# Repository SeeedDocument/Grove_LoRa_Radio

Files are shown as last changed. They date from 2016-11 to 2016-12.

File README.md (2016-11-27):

# Grove_LoRa_Radio
Grove LoRa Radio 433MHz SKU: 113060007

Grove LoRa Radio 868MHz SKU: 113060006

Change Log:

- 2016-11-27: create repos by Jiankai.li (jiankai.li@seeed.cc)

## About Seeed

Seeed is a hardware innovation platform for makers to grow inspirations into differentiating products. By working closely with technology providers of all scale, Seeed provides accessible technologies with quality, speed and supply chain knowledge. When prototypes are ready to iterate, Seeed helps productize 1 to 1,000 pcs using in-house engineering, supply chain management and agile manufacture forces. Seeed also team up with incubators, Chinese tech ecosystem, investors and distribution channels to portal Maker startups beyond.

## Contribution

We warmly welcome contribution to this documentation project. You can do this basically by [forking](https://help.github.com/articles/fork-a-repo), committing modifications and then [pulling requests](https://help.github.com/articles/using-pull-requests) (follow the links above for operating guide). Adding change log and your contact into file header is encouraged. Thanks for your contribution.

LICENSE
-------
Copyright (c) 2008-2016 Seeed Development Limited (www.seeedstudio.com / www.seeed.cc)

### Documents and Images
</a><br />
This work (product documents and associated images) are licensed under a <a rel="license" href="http://creativecommons.org/licenses/by-sa/4.0/">Creative Commons Attribution-ShareAlike 4.0 International License</a>. 

### Software Library
All demo software, code examples embedded in the document and any software libraray provided with the product document are licensed under [MIT License](https://github.com/SeeedDoc/WikiMigrationSync/blob/master/MIT_LICENSE "MIT LICENSE") unless otherwise specified.

### Thirdparty content
The resources provided with the product documents also contains datasheets, software examples and other content copyrighted by 3rd party authors and companies. All such items are copyright of respective owners. The use of such items are governed by their respective licenses.

All trademarks are the property of their respective owners.

### To Contact

Write to us at  with subject line "Wiki". Thanks

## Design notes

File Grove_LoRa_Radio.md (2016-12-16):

---
title: Grove - LoRa Radio
category: Communication
bzurl: https://www.seeedstudio.com
oldwikiname: Grove - LoRa Radio
prodimagename: Grove-LoRa Radio.jpg
surveyurl: https://www.research.net/r/Grove_LoRa_Radio
sku:  113060006/113060007
---

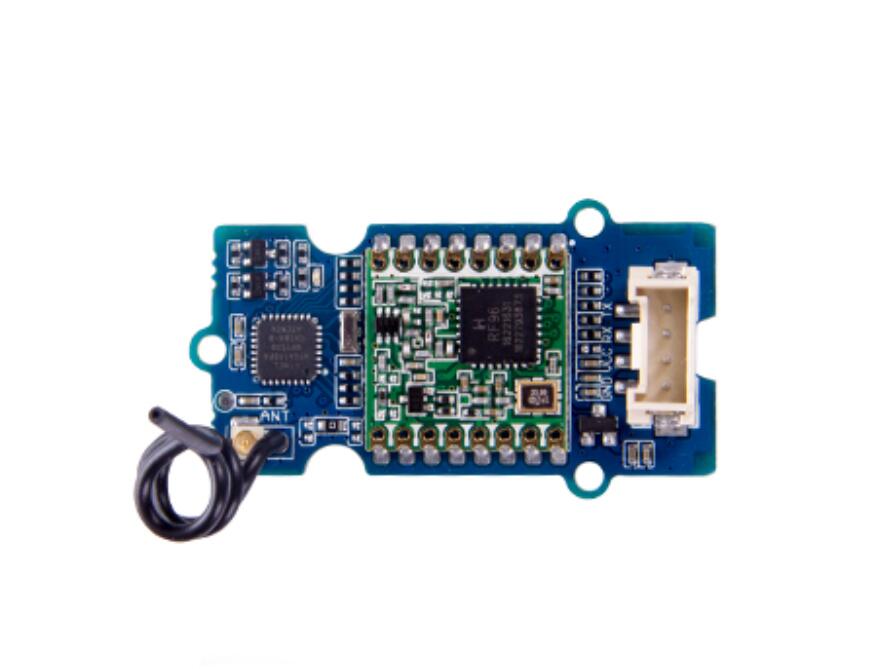
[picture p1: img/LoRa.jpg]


Grove - LoRa Radio is a wireless radio LoRa module with Grove Connector based on SX1276, it integrates richful features, like extra long communication, high penetrability, low consumption and etc.

Grove - LoRa Radio can help people to make their applications adapted in a longstanding, remotely and complex terrain condition. The communication of the distance of two LoRa node at least 2KM in a open field by the default antenna, and simultaneously people can add extra antenna to the reserved port.

Due to the spread spectrum technology, communications with different data rates do not interfere with each other. Data rates range from 0.3 kbps to 50 kbps.

(https://www.seeedstudio.com)

##  Features
---
- Using RFM95 module based on SX1276 LoRa®
- Working Voltage:5V/3.3V
- ~28mA(Avg) @+20dBm continuous transmit
- ~8.4mA(Avg)@standby mode
- ~20mA(Avg) @receive mode, BW-500kHz
- Working Temperature:-20 – 70℃
- Interface:Grove - UART(RX,TX,VCC,GND)
- Simple wire antenna or MHF Connector for external high gain antenna
- Working Frequency:868MHz/433MHz
- +20dBm 100 mW Power Output Capability
- Size:20*40mm
- Rate:0.3kps~50kps
- Ready-to-go Arduino libraries
- Resered MHF antenna connector

##  Interface Function
---

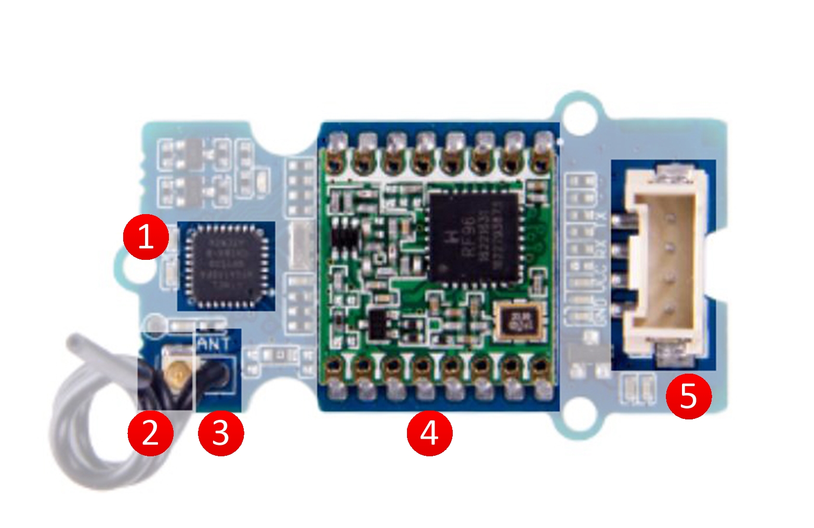
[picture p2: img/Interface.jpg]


1. ATMega168 MCU
2. MHF
3. ANT
4. RFM95 Module
5. Grove Interface

## Application Ideas
---
- Food
- Water
- Safety
- Health
- City IoT
- Sensor networks
- Long distance wireless communication

##Getting Started

After this section, you can make **Grove - LoRa Radio** run with only few steps.

###Preparations

Now we are making a demo for P2P(point to point) communication with the Grove - Lora Radio 433MHz, the Grrove - LoRa Radio 868MHz is the same way to use.

* [Seeeduino Lotus](https://www.seeedstudio.com/Seeeduino-Lotus-ATMega328-Board-with-Grove-Interface-p-1942.html)*2
* [Grove - LoRa Radio 433MHz](https://www.seeedstudio.com/)*2

If this is your first time using [Seeeduino Lotus](https://www.seeedstudio.com/Seeeduino-Lotus-ATMega328-Board-with-Grove-Interface-p-1942.html), please refer to [Seeeduino Lotus's wiki](http://www.seeedstudio.com/wiki/Seeeduino_Lotus_v1.0).

Seeeduino Lotus is fully compatible with Arduino which works as simple as Arduino.

If this is your first time using Arduino, Please put hand on [here](http://arduino.cc) to start your Arduino journey.

###Connecting hardware

[Seeeduino Lotus](https://www.seeedstudio.com/Seeeduino-Lotus-ATMega328-Board-with-Grove-Interface-p-1942.html) is a combination of Seeeduino and Base Shield. We can connect the LoRa Radio module to the D5 socket directly as the below picture shows.

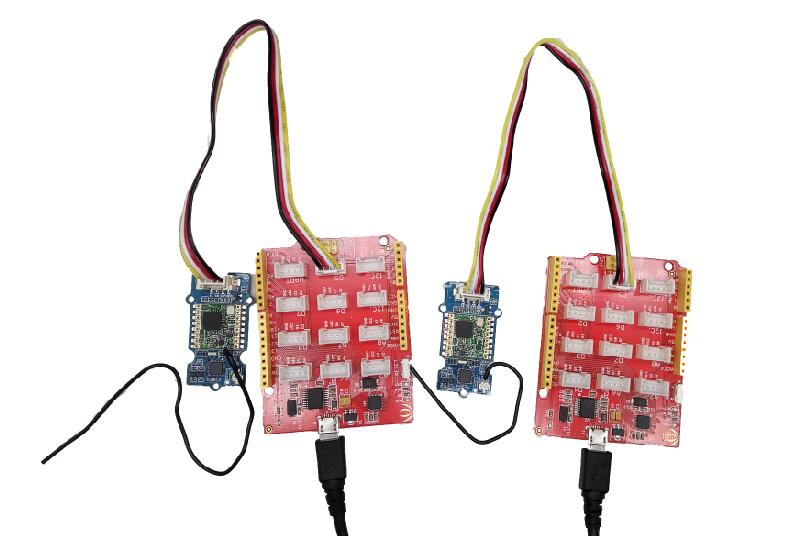
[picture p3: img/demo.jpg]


###Download

Click [here](https://github.com/Seeed-Studio/Grove_LoRa_433MHz_and_915MHz_RF/) to download the library and example code and decompress it to any folders(e.g. Drive D or desktop).

Now you need simple [configurations for Arduino](https://seeeddoc.github.io/Sketchbook%E7%9A%84%E4%BD%BF%E7%94%A8) sketchbook.

Launch Arduino IDE and click File>Preferences and add absolute location for downloaded testing code at Sketchbook location.

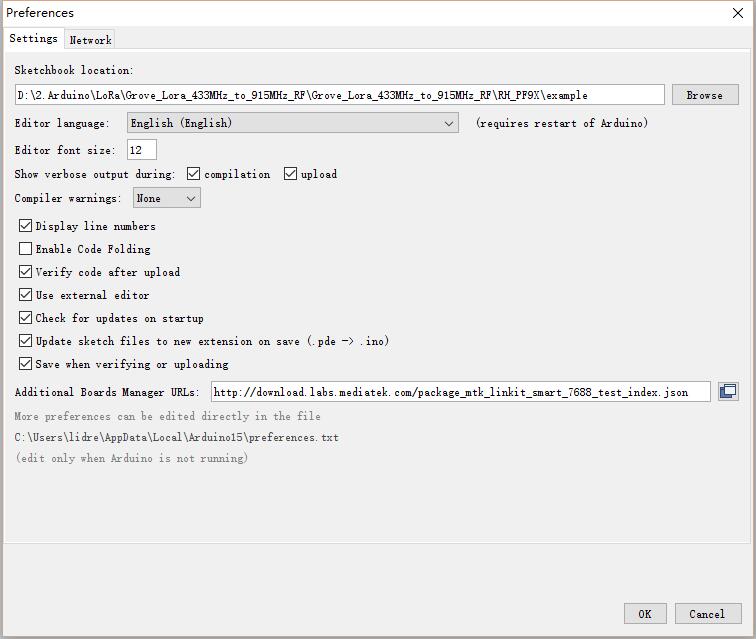
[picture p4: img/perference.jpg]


After configurations, please restart Arduino, click File>Sketchbook and choose rf95_client.

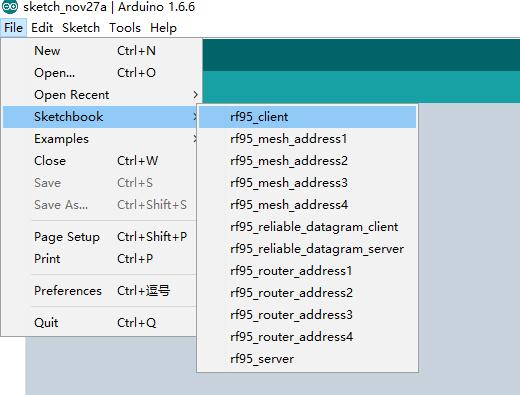
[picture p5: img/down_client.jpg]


Click Tools>Board to choose "Arduino/Genuino Uno" and select respective serial port.

Then connect another Seeeduino Lotus to PC and download rf95_server code.

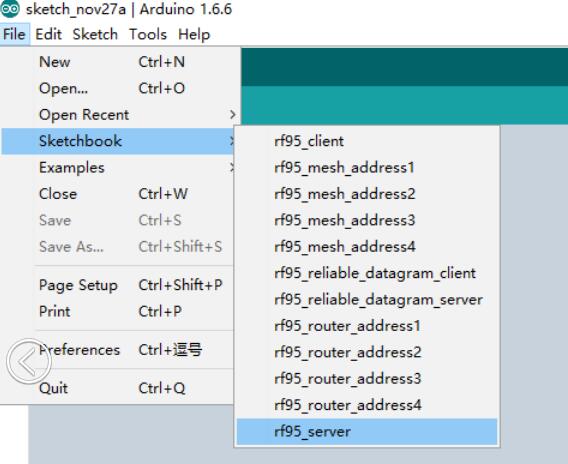
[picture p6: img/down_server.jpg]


**Note:**
If you're using Grove - LoRa Radio 868MHz module change the following code.

```c 

//rf95.setFrequency(434.0);
rf95.setFrequency(868.0);

```

###Review Results

After upload completed, you can open the serial monitor to see the result.

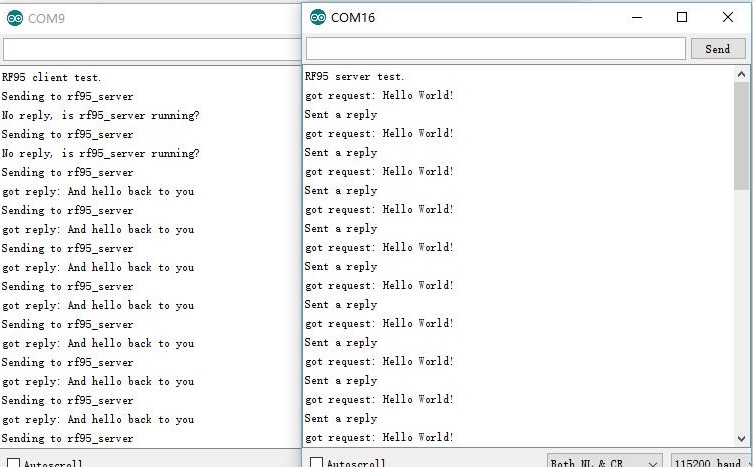
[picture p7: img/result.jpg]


###Data Rate

The below chart shows the relationships between the band rate signal band width spreding factor and sensitivity.

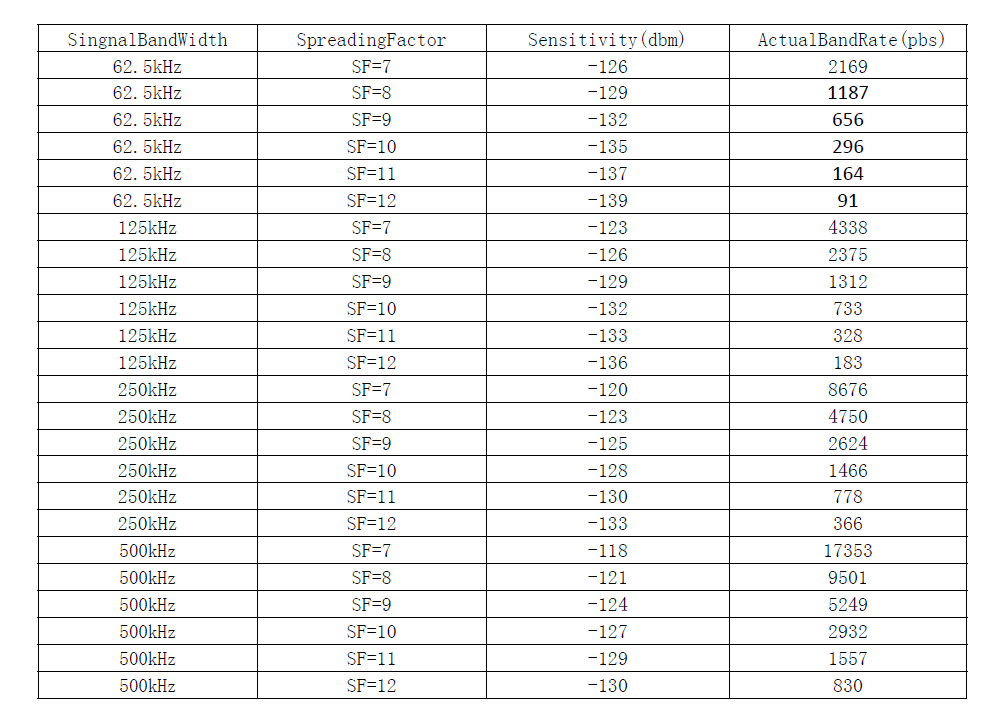
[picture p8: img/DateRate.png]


##  Resources
---
*   [Grove - LoRa Radio Library and Examples](https://github.com/Seeed-Studio/Grove_LoRa_433MHz_and_915MHz_RF/)
*   [Grove - LoRa Radio 433MHz v1.0 Schematics (Eagle files)](https://github.com/SeeedDocument/Grove_LoRa_Radio/blob/master/res/Grove%20-%20LoRa%20Radio%20433MHz%20v1.0sch.rar)
*   [Grove - LoRa Radio 433MHz v1.0 Schematics (PDF files)](https://github.com/SeeedDocument/Grove_LoRa_Radio/blob/master/res/Grove%20-%20LoRa%20Radio%20433MHz%20v1.0pdf.rar)
*   [Grove - LoRa Radio 433MHz v1.0 PCB (Eagle files)](https://github.com/SeeedDocument/Grove_LoRa_Radio/blob/master/res/Grove%20-%20LoRa%20Radio%20433MHz%20v1.0brd.rar)
*   [Grove - LoRa Radio 868MHz v1.0 Schematics (Eagle files)](https://github.com/SeeedDocument/Grove_LoRa_Radio/blob/master/res/Grove%20-%20LoRa%20Radio%20868MHz%20v1.0sch.rar)
*   [Grove - LoRa Radio 868MHz v1.0 Schematics (PDF files)](https://github.com/SeeedDocument/Grove_LoRa_Radio/blob/master/res/Grove%20-%20LoRa%20Radio%20868MHz%20v1.0pdf.rar)
*   [Grove - LoRa Radio 868MHz v1.0 PCB (Eagle files)](https://github.com/SeeedDocument/Grove_LoRa_Radio/blob/master/res/Grove%20-%20LoRa%20Radio%20868MHz%20v1.0brd.rar)
*   [LoRa Alliance](https://www.lora-alliance.org/)
*   [RFM95/96/97 Data Sheet](https://github.com/SeeedDocument/Grove_LoRa_Radio/blob/master/res/RFM95_96_97_98_DataSheet.pdf)

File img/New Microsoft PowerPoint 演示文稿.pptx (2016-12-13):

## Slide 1

Download Arduino Library

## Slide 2

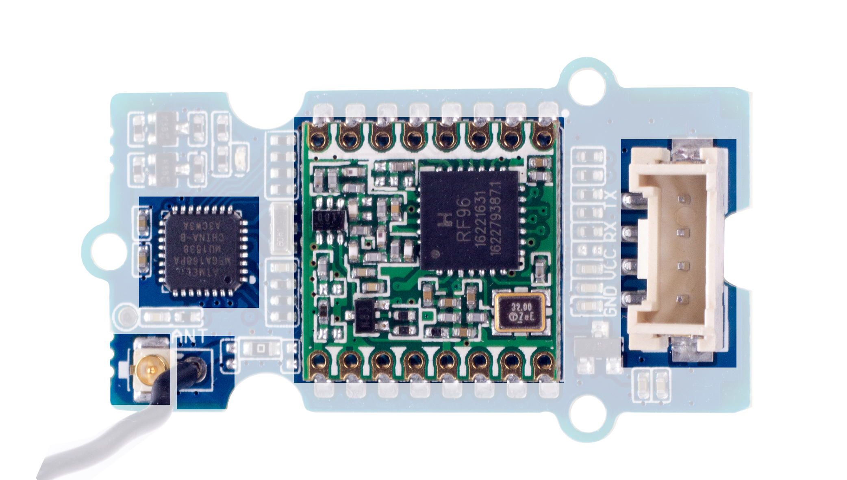
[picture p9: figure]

1

4

5

2

3

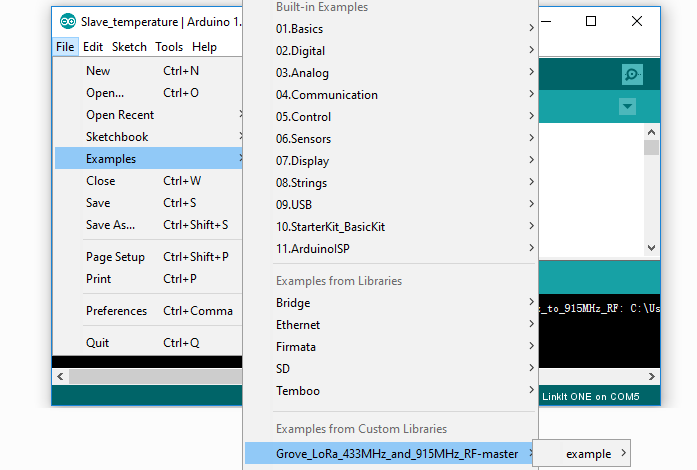
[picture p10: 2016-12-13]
img/library_2.png

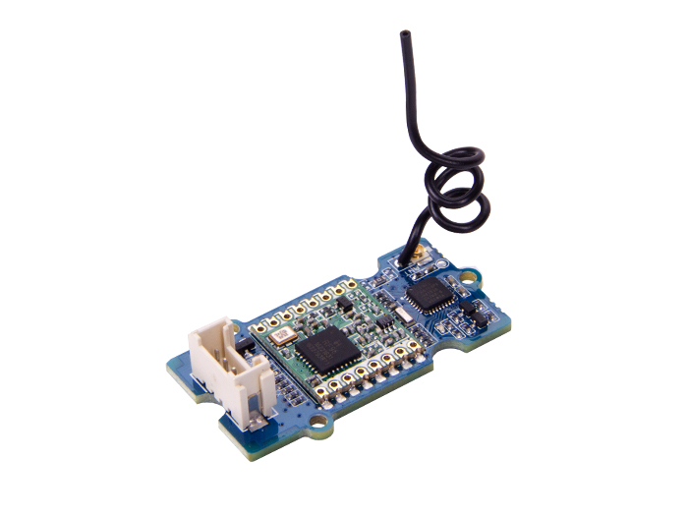
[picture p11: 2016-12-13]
img/cover.jpg

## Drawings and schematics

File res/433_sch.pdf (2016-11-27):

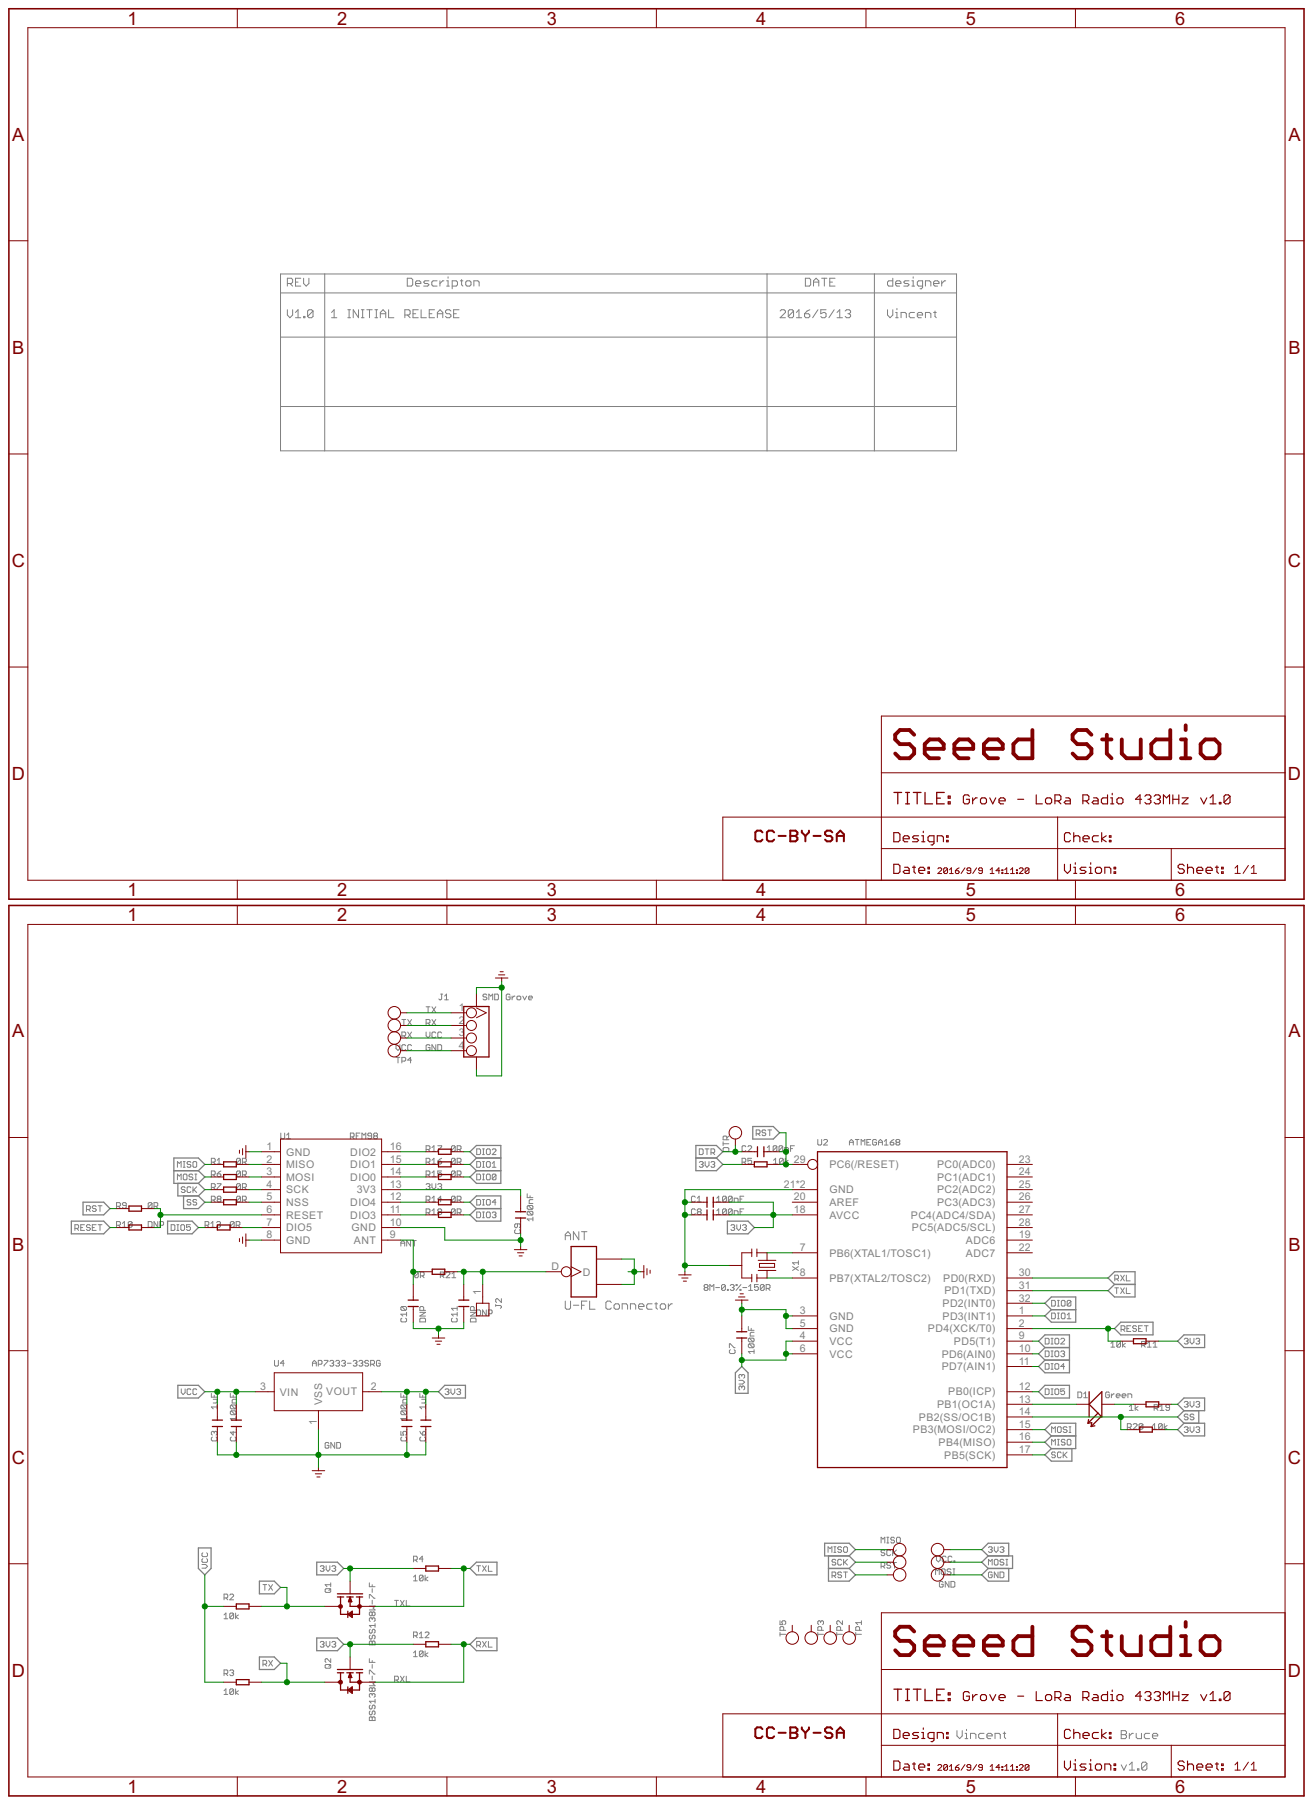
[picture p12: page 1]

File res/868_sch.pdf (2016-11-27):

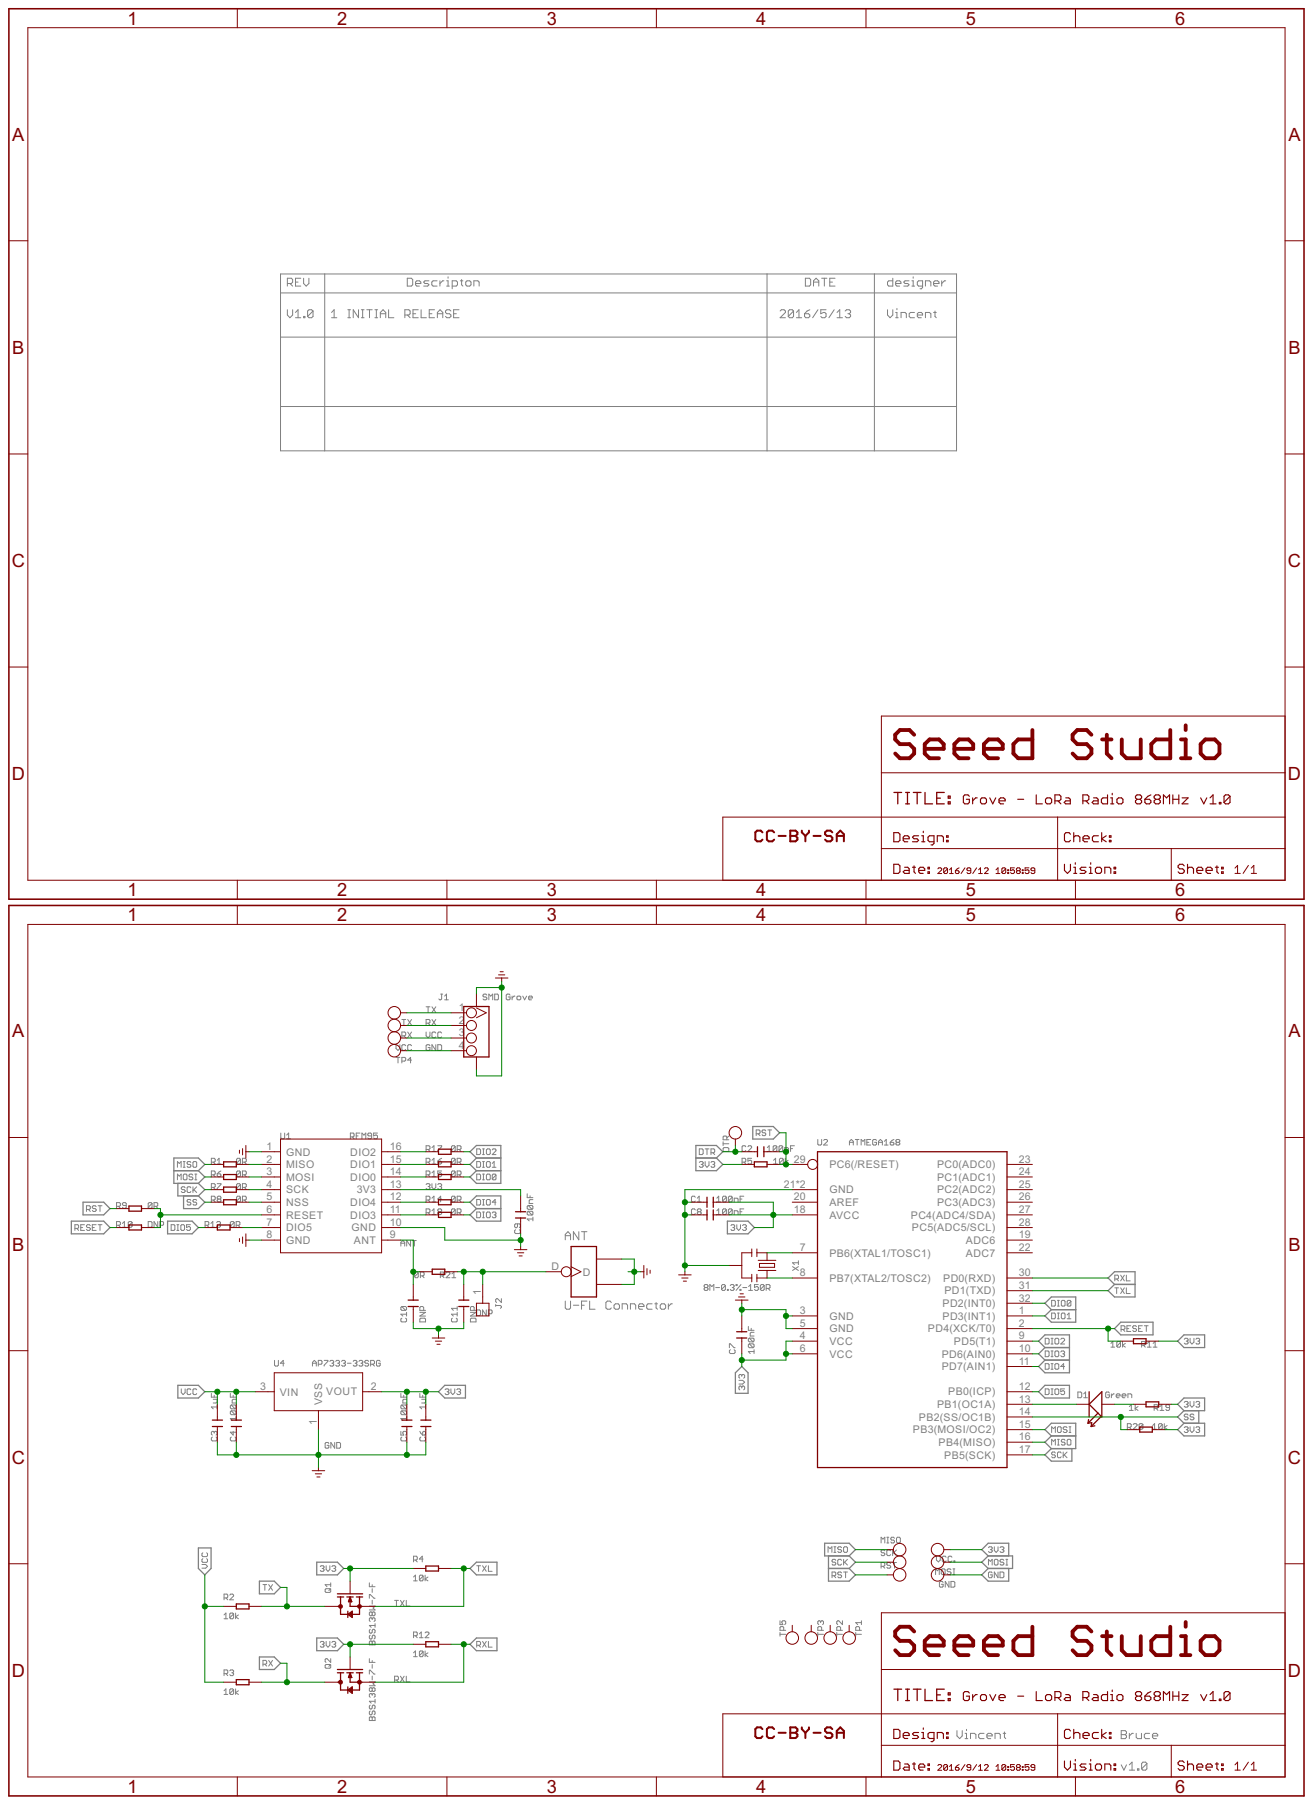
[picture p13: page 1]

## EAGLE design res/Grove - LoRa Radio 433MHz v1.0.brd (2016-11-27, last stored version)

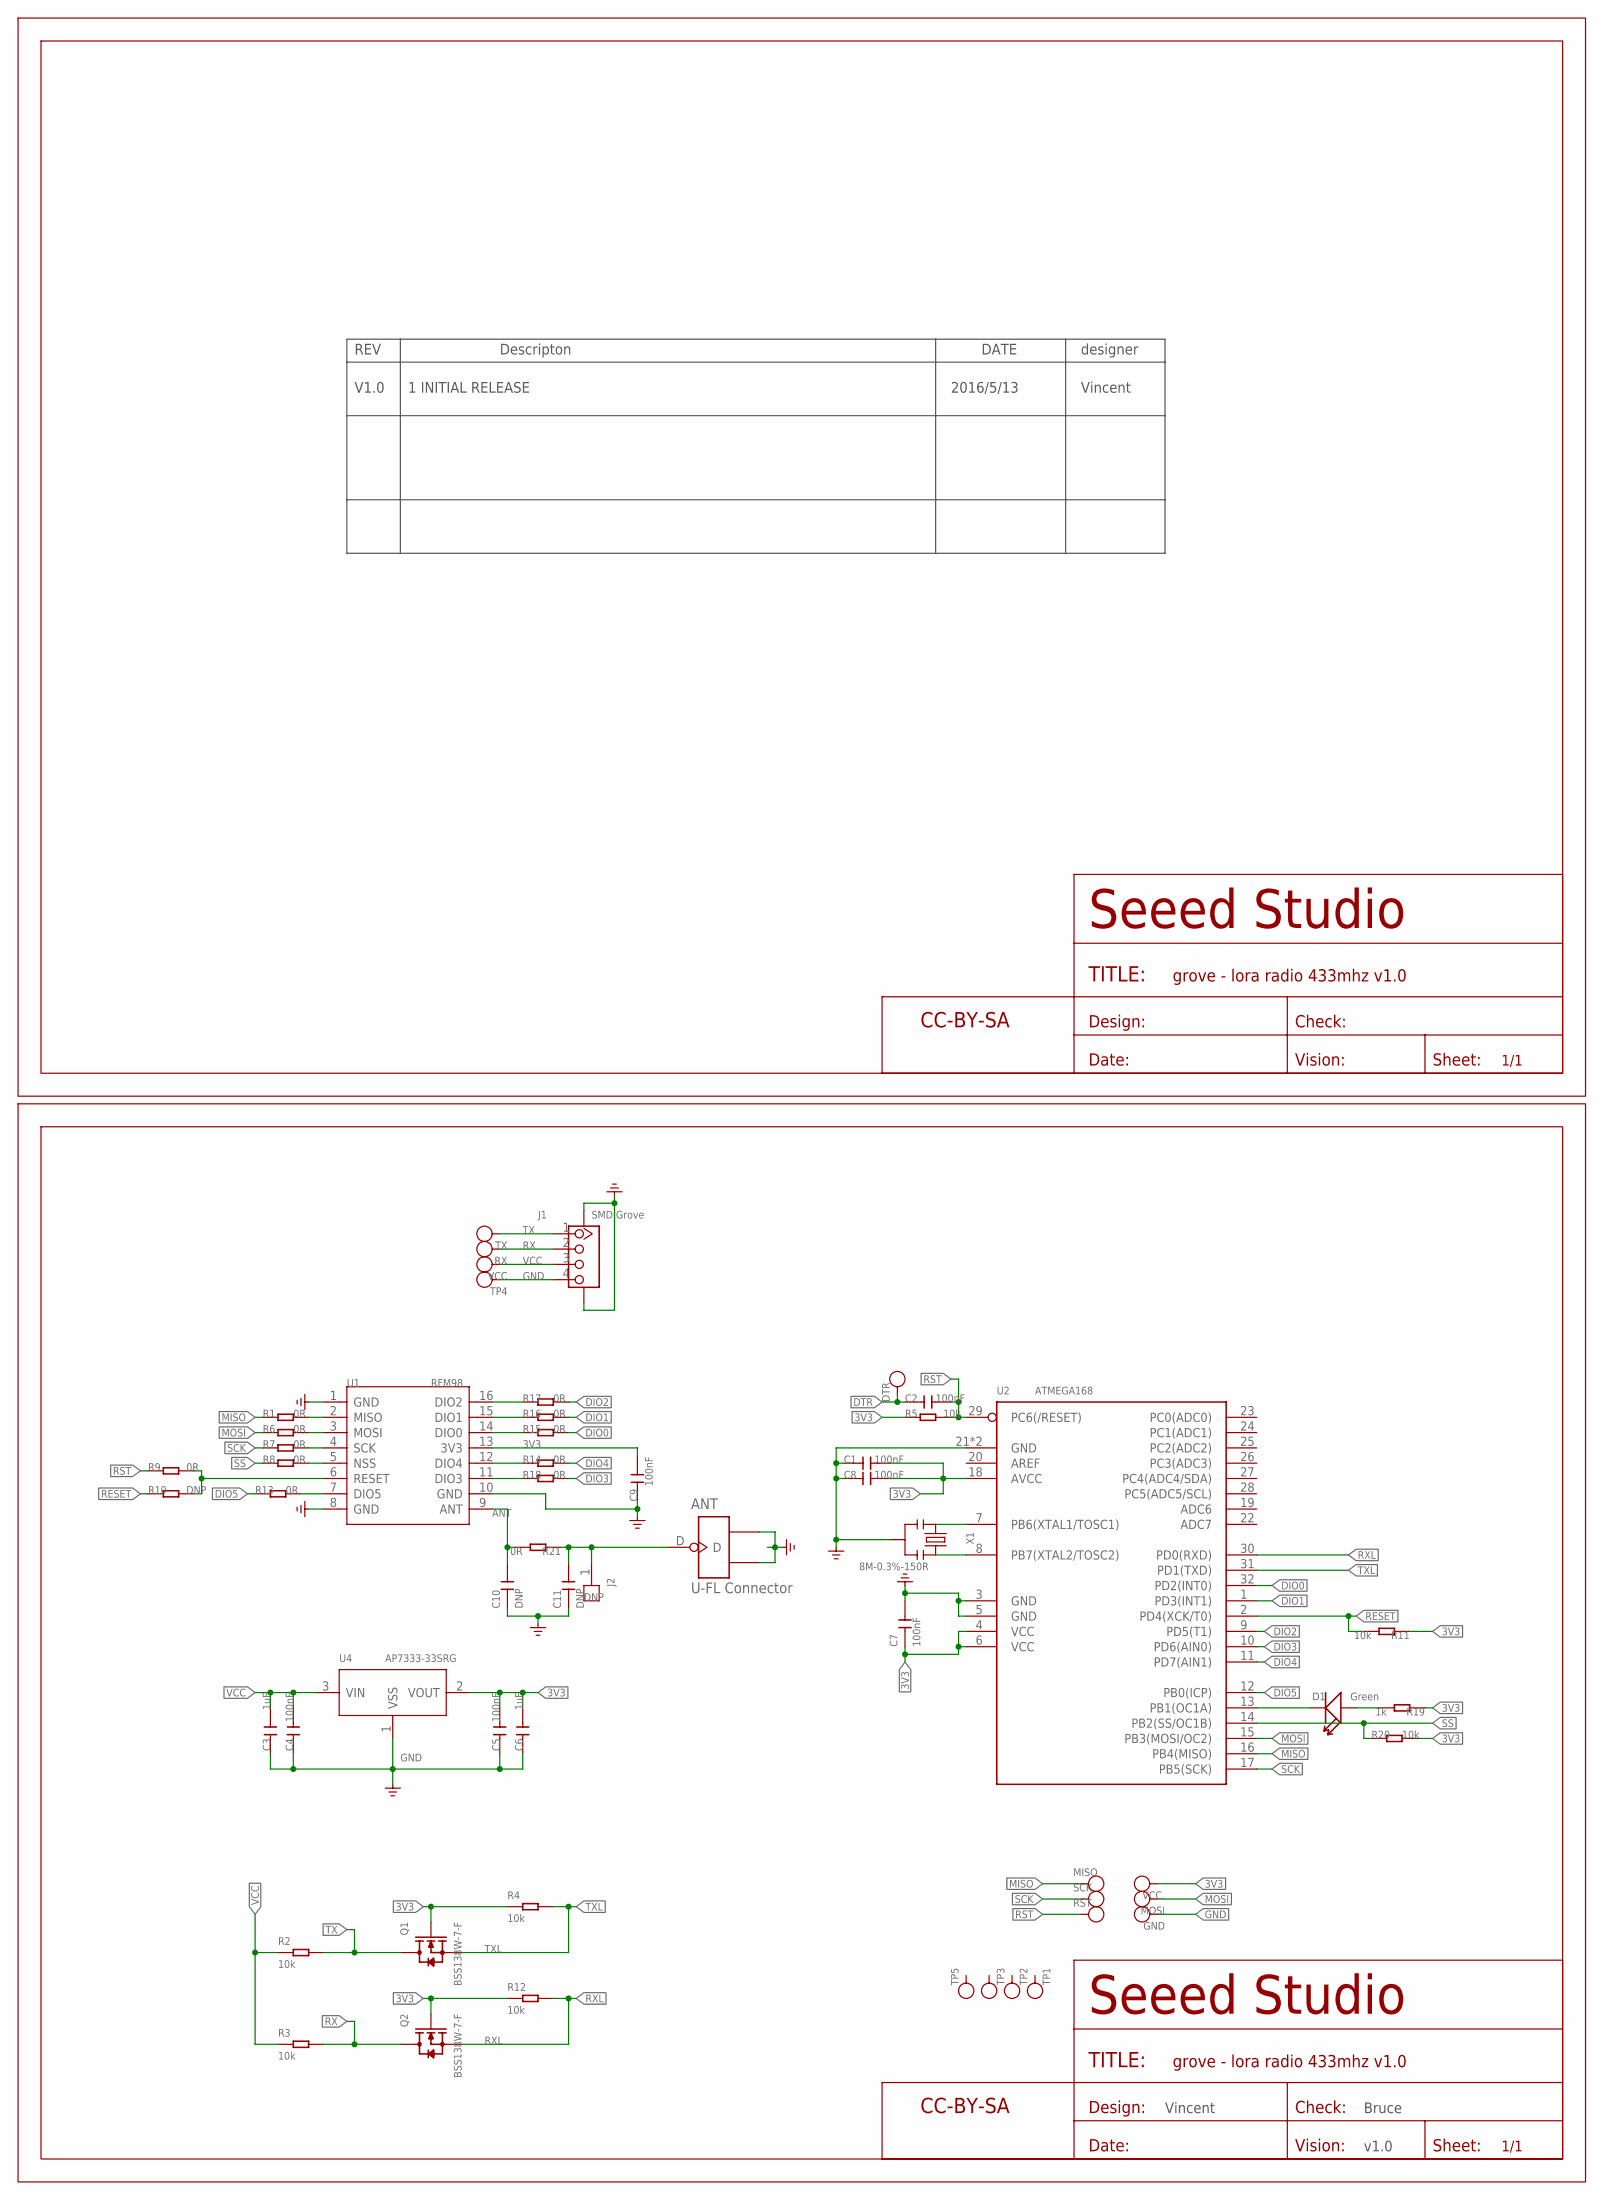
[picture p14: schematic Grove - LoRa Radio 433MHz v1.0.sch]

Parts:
ANT: U-FL Connector; U-FL3P-SMD-2.6X2.6X1.0MM
C1, C2, C4, C5, C7, C8, C9: 100nF; C0402
C3, C6: 1uF; C0402
C10, C11: DNP; C0402
D1: Green; LED-0402
DTR: TEST-POINT'4545'; TP-D45MIL
FR1, FR2: SEEEDSTUDIO-OPEN-SCH-FRAME; SEEEDSTUDIO-PCB-FRAME
GND: DNP; TP-D45MIL
J1: SMD Grove; HW4-SMD-2.0
J2: DNP; 1P-65/35MIL
MISO: DNP; TP-D45MIL
MOSI: DNP; TP-D45MIL
Q1, Q2: BSS138W-7-F; SOT-323
R1, R6, R7, R8, R9, R13, R14, R15, R16, R17, R18: 0R; R0402
R2, R3, R4, R5, R11, R12, R20: 10k; R0402
R10: DNP; R0402
R19: 1k; R0402
R21: 0R; R0603
RST: DNP; TP-D45MIL
RX: TEST-POINT'4545'; TP-D45MIL
SCK: DNP; TP-D45MIL
TP1, TP2, TP3, TP4, TP5: TEST-POINT'4545'; TP-D45MIL
TX: TEST-POINT'4545'; TP-D45MIL
U1: RFM98; MODEM16-2-16X16X1.8MM
U2: ATMEGA168; QFN32G-0.5-5X5MM
U4: AP7333-33SRG; SOT-23
VCC: TEST-POINT'4545'; TP-D45MIL
VCC.: NC; TP-D45MIL
X1: 8M-0.3%-150R; RESONATOR3-SMD-3.6X1.3X0.8MM

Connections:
3V3: C1.2, C5.1, C6.1, C7.1, C8.2, C9.2, Q1.1 (G), Q2.1 (G), R4.1, R5.2, R11.2, R12.1, R19.2, R20.2, U1.13 (3V3), U2.4 (VCC), U2.6 (VCC), U2.18 (AVCC), U4.2 (VOUT), VCC..T
ANT: C10.2, R21.2, U1.9 (ANT)
DIO0: R15.2, U2.32 (PD2(INT0))
DIO1: R16.2, U2.1 (PD3(INT1))
DIO2: R17.2, U2.9 (PD5(T1))
DIO3: R18.2, U2.10 (PD6(AIN0))
DIO4: R14.2, U2.11 (PD7(AIN1))
DIO5: R13.1, U2.12 (PB0(ICP))
DTR: C2.1, DTR.T
GND: ANT.GND1, ANT.GND2, C1.1, C3.2, C4.2, C5.2, C6.2, C7.2, C8.1, C9.1, C10.1, C11.1, GND.T, J1.4, J1.SS1, J1.SS2, TP4.T, U1.1 (GND), U1.8 (GND), U1.10 (GND), U2.3 (GND), U2.5 (GND), U2.21 (GND), U2.33 (GND), U4.1 (VSS), X1.2
MISO: MISO.T, R1.1, U2.16 (PB4(MISO))
MOSI: MOSI.T, R6.1, U2.15 (PB3(MOSI/OC2))
unnamed: R13.2, U1.7 (DIO5)
unnamed: R17.1, U1.16 (DIO2)
unnamed: R9.1, R10.1, U1.6 (RESET)
unnamed: R16.1, U1.15 (DIO1)
unnamed: R15.1, U1.14 (DIO0)
unnamed: R14.1, U1.12 (DIO4)
unnamed: R1.2, U1.2 (MISO)
unnamed: R6.2, U1.3 (MOSI)
unnamed: R7.2, U1.4 (SCK)
unnamed: R8.2, U1.5 (NSS)
unnamed: R18.1, U1.11 (DIO3)
unnamed: D1.-, U2.13 (PB1(OC1A))
unnamed: D1.+, R19.1
unnamed: ANT.D, C11.2, J2.1, R21.1
RESET: R10.2, R11.1, U2.2 (PD4(XCK/T0))
RST: C2.2, R5.1, R9.2, RST.T, U2.29 (PC6(/RESET))
RX: J1.2, Q2.3 (D), R3.2, RX.T
RXL: Q2.2 (S), R12.2, U2.30 (PD0(RXD))
SCK: R7.1, SCK.T, U2.17 (PB5(SCK))
SS: R8.1, R20.1, U2.14 (PB2(SS/OC1B))
TX: J1.1, Q1.3 (D), R2.2, TX.T
TXL: Q1.2 (S), R4.2, U2.31 (PD1(TXD))
VCC: C3.1, C4.1, J1.3, R2.1, R3.1, U4.3 (VIN), VCC.T
XTAL1: U2.7 (PB6(XTAL1/TOSC1)), X1.1
XTAL2: U2.8 (PB7(XTAL2/TOSC2)), X1.3

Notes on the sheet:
REV
Descripton
DATE
designer
V1.0
1 INITIAL RELEASE
2016/5/13
Vincent
Bruce
v1.0

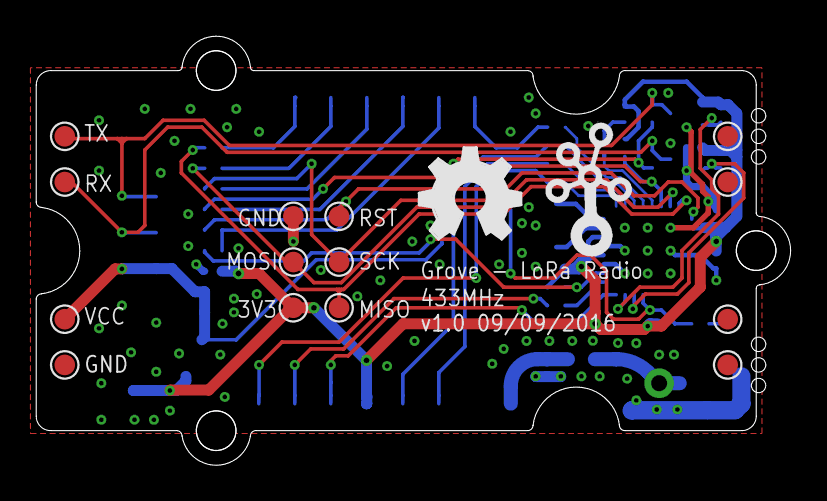
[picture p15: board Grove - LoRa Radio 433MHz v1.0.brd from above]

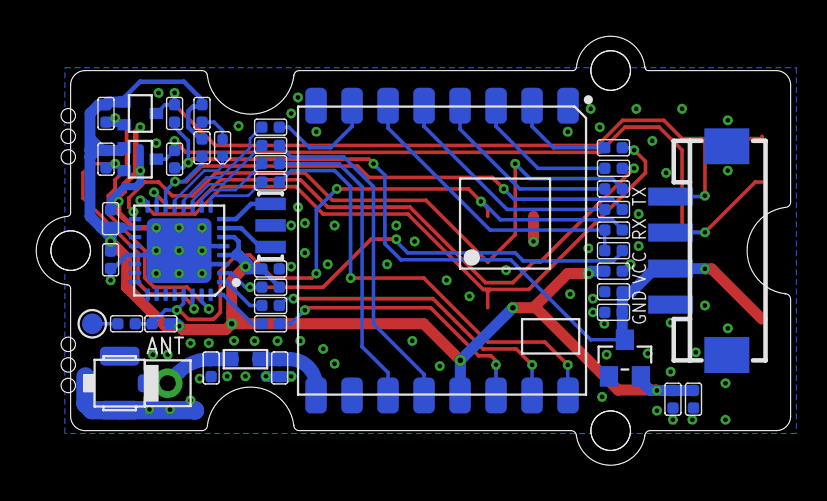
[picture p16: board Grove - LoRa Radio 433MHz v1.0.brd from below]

Board: 2 copper layers, 41.9 x 23.8 mm, 62 parts (46 on the bottom side), 37 nets.

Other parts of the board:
U$2: OSHW_FILLX200_NOTEXT
U$4: GROVE-1*2-TEST-PLATFORM-TOP
U$8: GROVE-SILK-BIG

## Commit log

2016-11-27 add the res
    [Grove - LoRa Radio 433MHz v1.0.brd, Grove - LoRa Radio 433MHz v1.0.sch, Grove - LoRa Radio 868MHz v1.0.brd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]
2016-11-27 add res
    [Grove - LoRa Radio 433MHz v1.0.brd, Grove - LoRa Radio 433MHz v1.0.sch, Grove - LoRa Radio 868MHz v1.0.brd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]

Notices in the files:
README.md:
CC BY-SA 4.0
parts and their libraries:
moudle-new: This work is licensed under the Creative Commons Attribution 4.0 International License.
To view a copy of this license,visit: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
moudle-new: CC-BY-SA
